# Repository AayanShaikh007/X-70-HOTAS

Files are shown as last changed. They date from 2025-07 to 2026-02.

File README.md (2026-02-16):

# X-70 HOTAS

A throttle and joystick HOTAS system designed from the ground up. Modelled after the X-56 HOTAS by Logitech. 

The X-70 HOTAS is a flight control system designed for use in flight sims and space sims. HOTAS stands for Hands on Throttle and Stick, and they are used to control planes in flight simulators just like how Airbus pilots and fighter pilots use a joystick to control the plane's movements. I designed both the throttle and the joystick in this project, down to the very mechanism that their motion relies on. The X-70 is highly customizable and has a bunch of useful features that increase realism, including landing gear and flap change levers, various customizable switches, and a touchscreen display that can be customized to activate more features and display data. 

I was motivated to make this project mainly by my own interest in flight sims but also due to the fact that there arent many HOTAS systems on the market right now that have a comparable amount of features for a reasonable price. For instance, the Turtle Beach VelocityOne flightdeck goes for around $500 CAD, which isnt very affordable. There is a lack of a affordable mid series detached HOTAS system that is still capable and reliable. 

## Software
I intend on using FreeJoy, a open source software to configure and run the joystick and throttle. It should allow me to easily configure the parts and make it much easier to debug issues and reduce workload since I wouldnt have to make a entire software just for the hotas. 

Freejoy: https://github.com/FreeJoy-Team/FreeJoy 

## Wiring Diagram
The wiring diagram is located inside the PCB folder as wiringdiagram.pdf. This will apply for throttle, the joystick does not need a matrix board but I may add one for convencience (I will get 5 pcbs from jlcpcb anyways). 

# Project Showcase







# BOM 
| Item | Amount | Bought? | Cost (CAD) | Total Cost | Notes | Link |
|---|---|---|---|---|---|---|
| Bluepill Microcontroller | 2 | n | 5.65 | 11.3 | | [Link](https://www.aliexpress.com/item/1005004918334754.html) |
| usb c to a cables | 2 | n | 2.86 | 5.72 | | [Link](https://www.aliexpress.com/item/1005007504310983.html) |
| toggle switches | 6 | n | 4.10 | 24.6 | | [Link](https://www.aliexpress.com/item/1005001315963290.html) |
| potentiometers (7mm thread) | 5 | n | 2.53 | 12.65 | cheapest option | [Link](https://www.aliexpress.com/item/1005005661105692.html) |
| rotary encoders (7mm thread)| 6 | n | 4.83 | 28.98 | looking for alternatives | [Link](https://www.aliexpress.com/item/1005007737001031.html) |
| large momentary switch | 1 | n | 6.63 | 6.63 | | [Link](https://aliexpress.com/item/4001169879232.html) |
| large latching switch | 1 | n | 6.76 | 6.76 | | [Link](https://aliexpress.com/item/4001169879232.html) |
| mini joysticks | 3 | n | 2.17 | 6.51 | kinda small but should work | [Link](https://www.aliexpress.com/item/1005007260466379.html) |
| large rgb metal button | 2 | n | 1.92 | 3.84 | | [Link](https://www.aliexpress.com/item/4000830670631.html) |
| hat switches 8 way | 3 | n | 4.57 | 13.71 | should be able to print cap | [Link](https://www.aliexpress.com/item/1005002969535551.html) |
| tricolor landing lights | 3 | n | 3.31 | 9.93 | | [Link](https://www.aliexpress.com/item/1005006314855864.html) |
| Nextion Enhanced | 1 | n | 27.2 | 27.2 | lots of models, shipping will vary | [Link](https://www.aliexpress.com/item/4001240732911.html) |
| 5x11x5 bearings | 2 | n | 1.38 | 2.76 | | [Link](https://www.aliexpress.com/item/1005006224445582.html) |
| m5x22 max screws | 4 | n | 0.51 | 2.03 | different size | [Link](https://www.aliexpress.com/item/1005005879037174.html) |
| M3x0.5 by 7 max screws | 6 | n | 1.38 | 1.38 | | [Link](https://www.aliexpress.com/item/1005004527586307.html) |
| m5 by 30 max screws | 8 | n | 0.42 | 3.36 | different size | [Link](https://www.aliexpress.com/item/1005005879037174.html) |
| springs | 4 | n | 5.01 | 5.01 | | [Link](https://www.aliexpress.com/item/1005006443579464.html) |
| hall effect sensors | 2 | n | 8.39 | 8.39 | | [Link](https://www.aliexpress.com/item/1005008473344808.html) |
| PCB manufacturing | 1 | n | 4.74 | 4.74 | | no link |

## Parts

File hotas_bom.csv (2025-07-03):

Item | Amount | Bought? | Cost (CAD) | Total Cost | Notes | Link
Bluepill Microcontroller | 2 | n | 5.65 | 11.3 |  | https://www.aliexpress.com/item/1005004918334754.html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
usb c to a cables | 2 | n | 2.86 | 5.72 |  | https://www.aliexpress.com/item/1005007504310983.html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
toggle switches | 6 | n | 4.10 | 24.6 |  | https://www.aliexpress.com/item/1005001315963290.html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
potentiometers (7mm thread) | 5 | n | 2.53 | 12.65 | cheapest option | https://www.aliexpress.com/item/1005005661105692.html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
rotary encoders (7mm thread) | 6 | n | 4.83 | 28.98 | looking for alternatives | https://www.aliexpress.com/item/1005007737001031.html?scm_id=1007.40050.354490.0&scm-url=1007.40050.354490.0
large momentary switch | 1 | n | 6.63 | 6.63 |  | aliexpress.com/item/4001169879232.html?spm=a2g0o.productlist.main.1.23fdLvQCLvQCRK&algo_pvid=6f283221-de15-417a-9911-344e72dfff53&algo_exp_id=6f283221-de15-417a-9911-344e72dfff53-0&pdp_ext_f=%7B"order"%3A"358"%2C"eval"%3A"1"%7D&pdp_npi=4%40dis%21CAD%216.68%215.57%21%21%214.76%213.97%21%402103205217508267992468400e6bad%2110000015016525249%21sea%21CA%210%21ABX&curPageLogUid=WL6grQlmlbEs&utparam-url=scene%3Asearch%7Cquery_from%3A#nav-description
large latching switch | 1 | n | 6.76 | 6.76 |  | aliexpress.com/item/4001169879232.html?spm=a2g0o.productlist.main.1.23fdLvQCLvQCRK&algo_pvid=6f283221-de15-417a-9911-344e72dfff53&algo_exp_id=6f283221-de15-417a-9911-344e72dfff53-0&pdp_ext_f=%7B"order"%3A"358"%2C"eval"%3A"1"%7D&pdp_npi=4%40dis%21CAD%216.68%215.57%21%21%214.76%213.97%21%402103205217508267992468400e6bad%2110000015016525249%21sea%21CA%210%21ABX&curPageLogUid=WL6grQlmlbEs&utparam-url=scene%3Asearch%7Cquery_from%3A#nav-description
mini joysticks | 3 | n | 2.17 | 6.51 | kinda small but should work | https://www.aliexpress.com/item/1005007260466379.html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
large rgb metal button | 2 | n | 1.92 | 3.84 |  | https://www.aliexpress.com/item/4000830670631.html?scm_id=1007.40050.354490.0&scm-url=1007.40050.354490.0 or https://www.aliexpress.com/item/1005006477375437.html?scm_id=1007.40050.354490.0&scm-url=1007.40050.354490.0
hat switches 8 way | 3 | n | 4.57 | 13.71 | should be able to print cap | https://www.aliexpress.com/item/1005002969535551.html?scm_id=1007.40050.354490.0&scm-url=1007.40050.354490.0
tricolor landing gear lights | 3 | n | 3.31 | 9.93 |  | https://www.aliexpress.com/item/1005006314855864.html?scm_id=1007.10668.445195.0&scm-url=1007.10668.445195.0
Nextion Enhanced | 1 | n | 27.2 | 27.2 | lots of models, shipping will vary | https://www.aliexpress.com/item/4001240732911.html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
5x11x5 bearings | 2 | n | 1.38 | 2.76 |  | https://www.aliexpress.com/item/1005006224445582.html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
m5x22 max screws | 4 | n | 0.51 | 2.030266667 | different size | https://www.aliexpress.com/item/1005005879037174.html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
M3x0.5 by 7 max screws | 6 | n | 1.38 | 1.38 |  | https://www.aliexpress.com/item/1005004527586307.html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
m5 by 30 max screws | 8 | n | 0.42 | 3.36 | different size | https://www.aliexpress.com/item/1005005879037174.html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
springs | 4 | n | 5.01 | 5.01 |  | https://www.aliexpress.com/item/1005006443579464.html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
hall effect sensors | 2 | n | 8.39 | 8.39 |  | https://www.aliexpress.com/item/1005008473344808.html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
PCB Manufacturing | 1 | n | 4.74 | 4.74
 |  |  | CAD | USD
 |  | Total Cost | 185.50 | 136.45
 |  |  |  | Note: 150 USD = 204.58 CAD

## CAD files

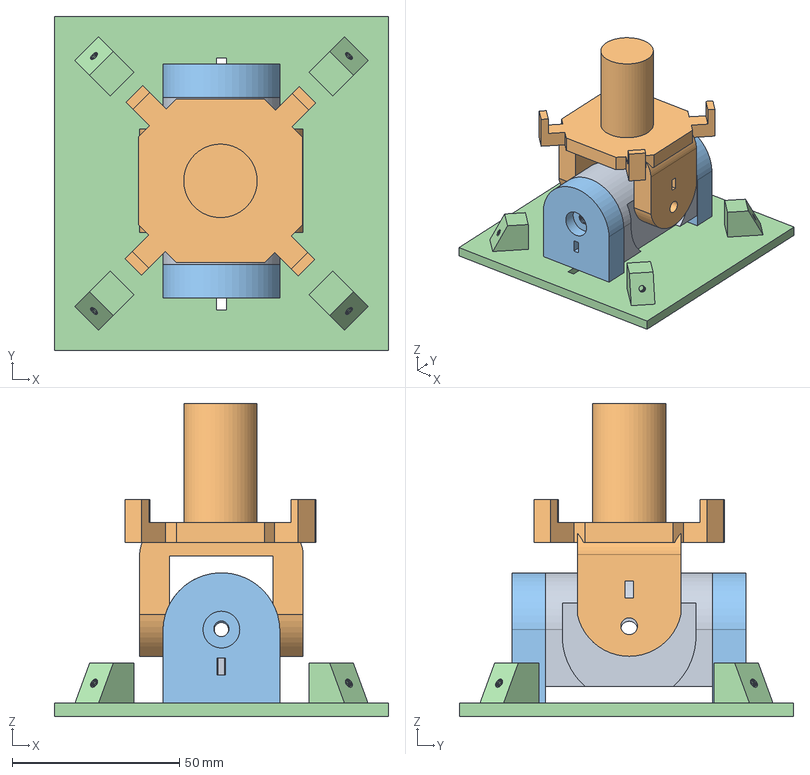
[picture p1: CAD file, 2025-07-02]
CAD/joystick_assembled v13.step
100.0 x 100.0 x 93.8 mm
roll
pitch
roll brackets x 2
base

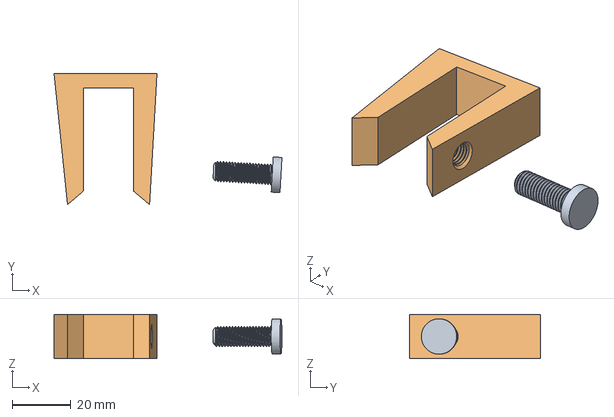
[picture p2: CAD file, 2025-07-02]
CAD/clamp v2.step
77.5 x 44.6 x 15.0 mm
bolt

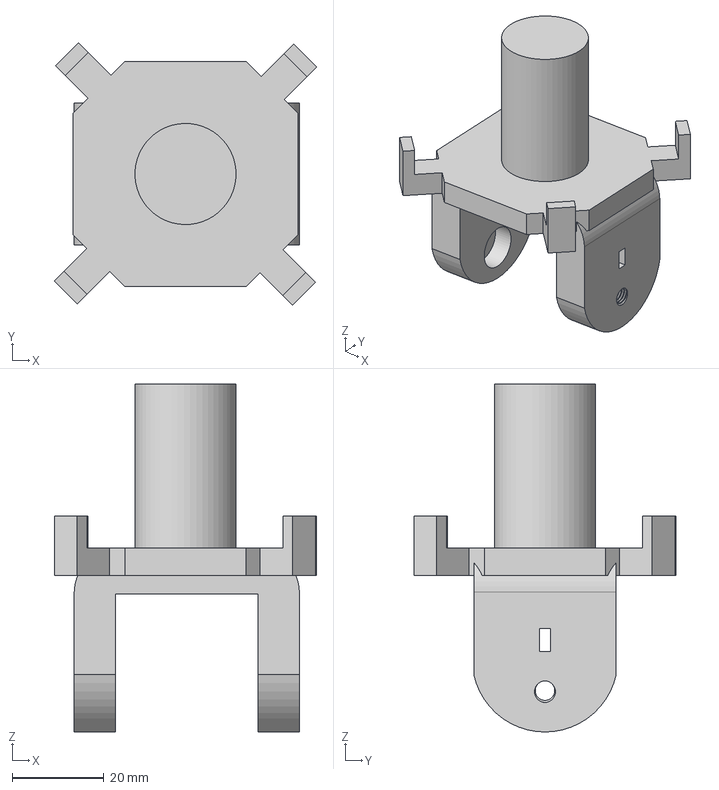
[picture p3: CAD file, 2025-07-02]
CAD/pitch v12.step
57.1 x 57.1 x 75.7 mm

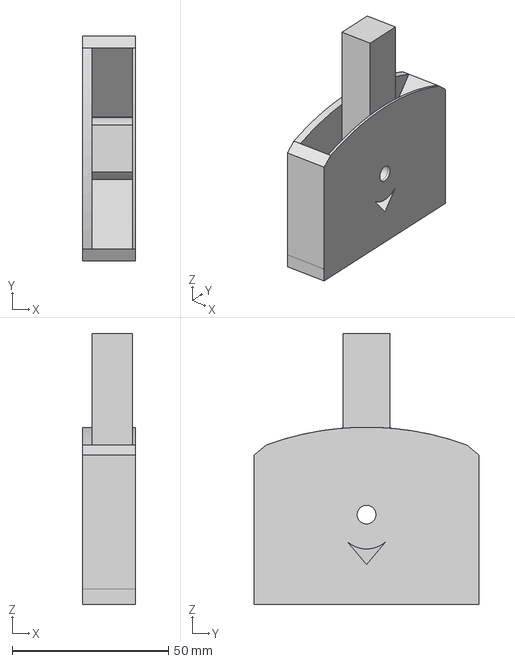
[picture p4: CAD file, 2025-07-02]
CAD/throttle_mech v6.step
17.0 x 72.0 x 86.8 mm

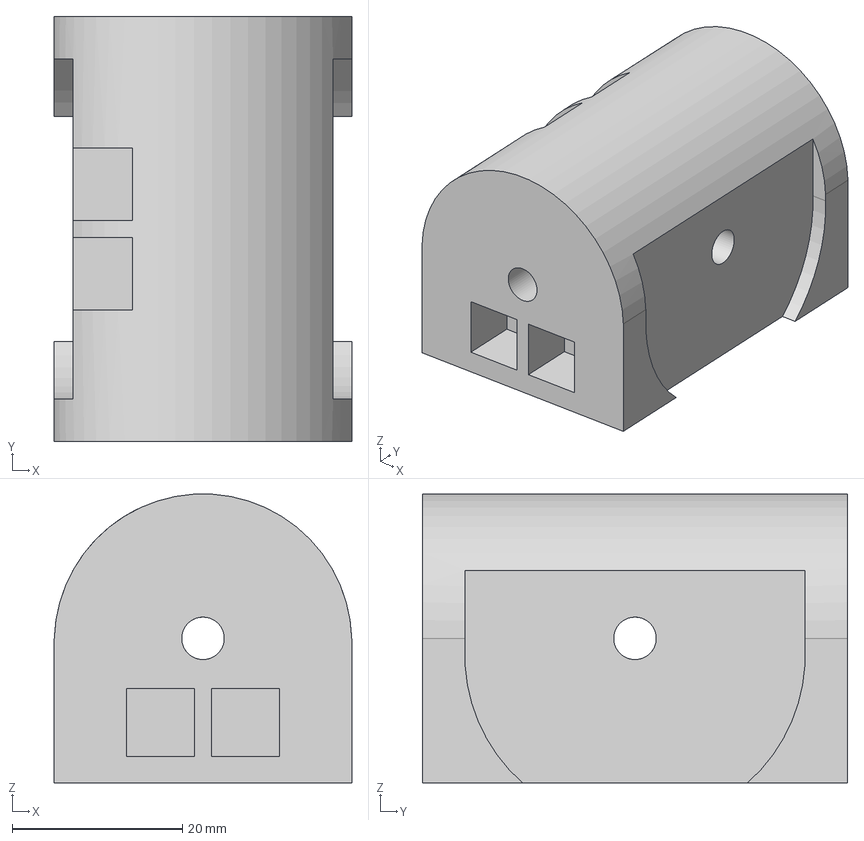
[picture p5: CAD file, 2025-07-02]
CAD/roll v9.step
35.0 x 50.0 x 34.0 mm

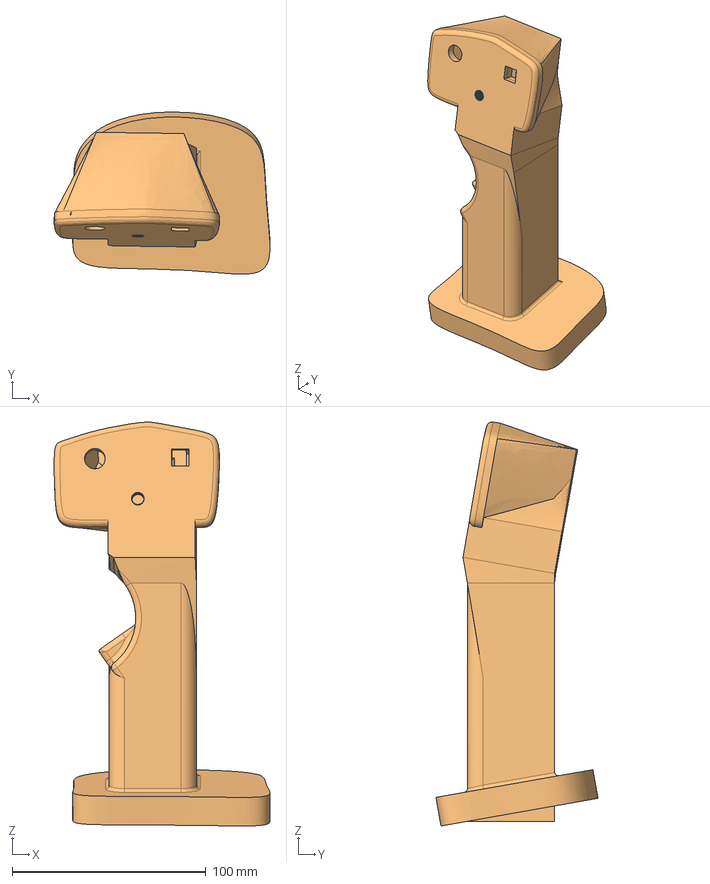
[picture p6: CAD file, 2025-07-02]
CAD/joystick v10.step
111.4 x 83.7 x 208.6 mm

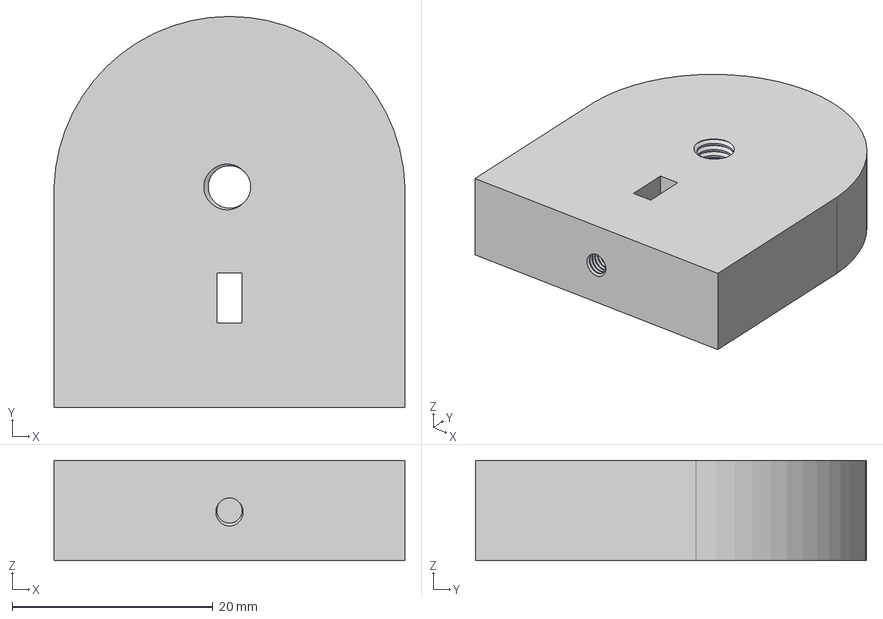
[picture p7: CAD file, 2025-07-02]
CAD/roll brackets v8.step
35.0 x 39.0 x 10.0 mm

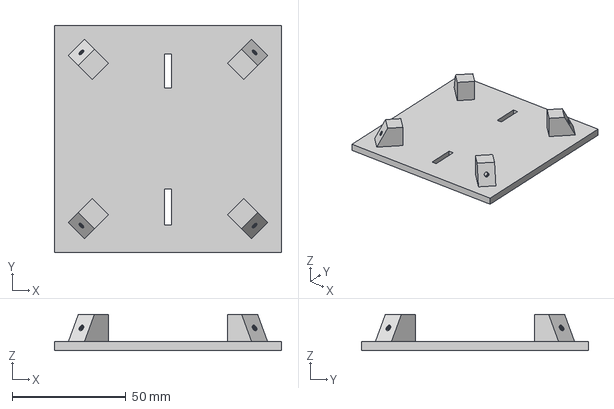
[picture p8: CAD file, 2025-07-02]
CAD/base v9.step
100.0 x 100.0 x 16.0 mm

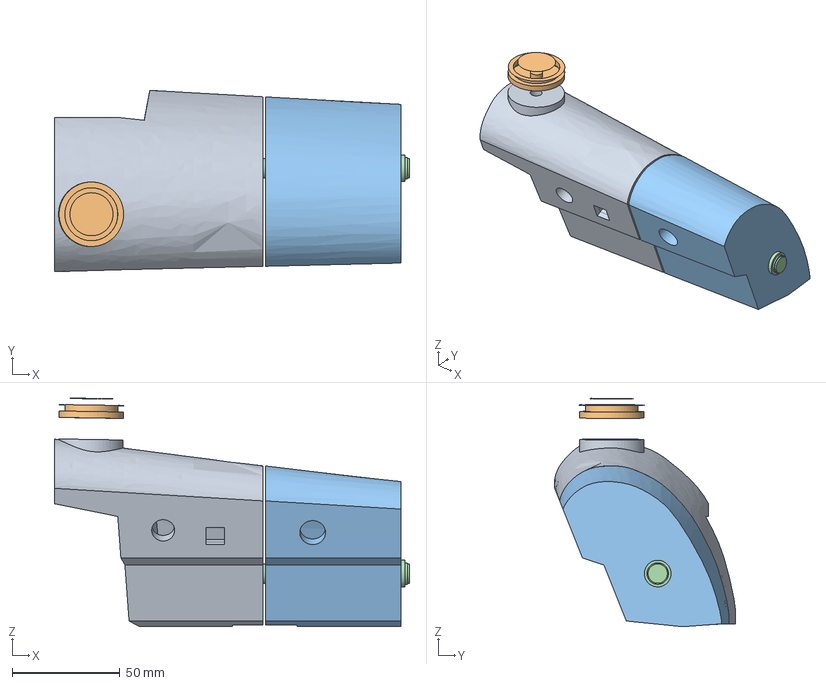
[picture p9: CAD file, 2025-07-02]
CAD/throttle_handle v10.step
165.0 x 84.3 x 106.2 mm

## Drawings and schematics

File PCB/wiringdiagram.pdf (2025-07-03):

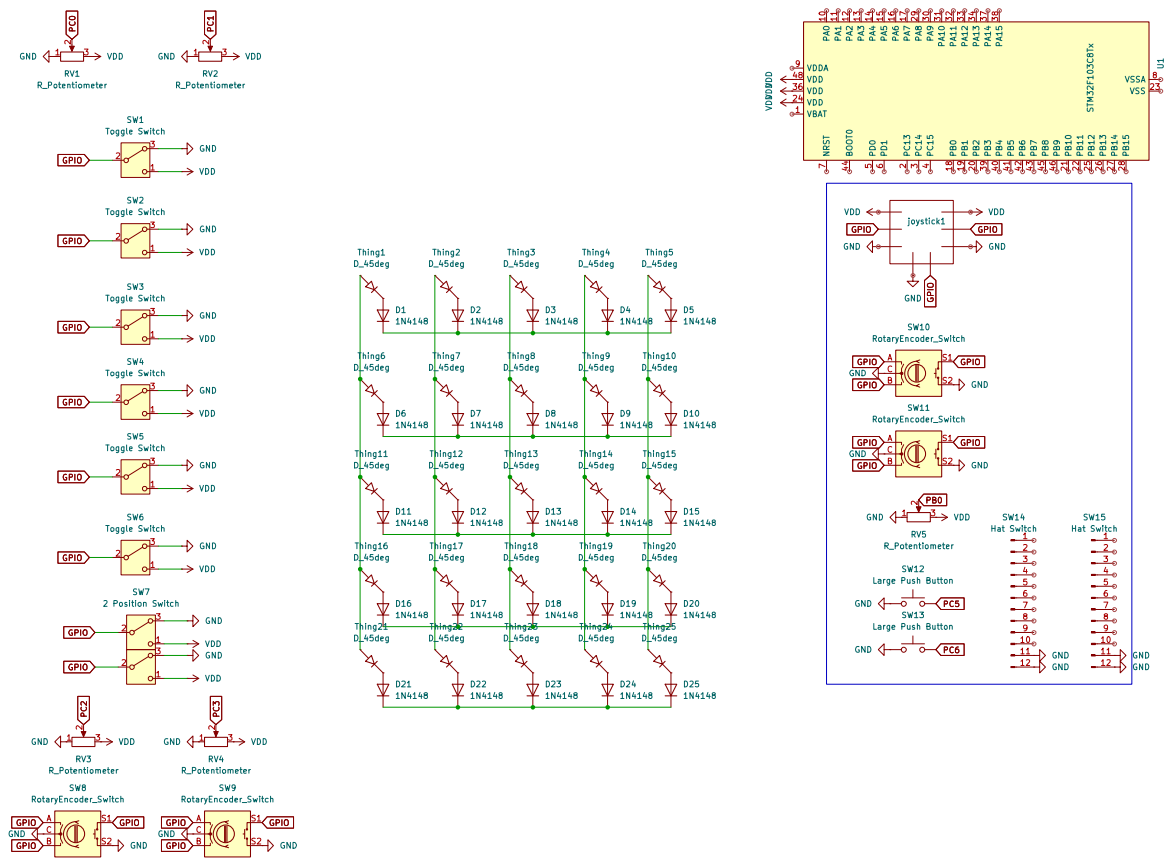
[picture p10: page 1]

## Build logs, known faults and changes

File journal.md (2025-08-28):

---
title: "X-70 HOTAS"
author: "@Scalar"
description: "A throttle and joystick HOTAS system for flight sims."
created_at: "2025-06-16"
---

# X-70 HOTAS Journal --> 49 Hours total (not including assembly)
First- a small word on the complexity of the project. I think this was a particularly difficult project and should be considered to take 50+ hours since I will likely be making various edits and changes in the future as I prototype the throttle and joystick mechanisms and expereiment with making new ones. Furthermore, assembly and software configuration will also take quite some time. 

# June 16th- spent 4 hours planning. 
I spent most of today setting my goals for the project. In summary, I want to make a HOTAS system that resembles the X-56 HOTAS by Logitech, since I like its design. 

_Aims for CAD design_
- X and Y moving body, detect position via hall effect sensors
- Ergonomic flight stick
- Analog trigger spring mechanisms

_Aims for electronics_
- Force feedback
- Use FreeJoy and any STM32F103 ("Blue Pill"). This removes the need for software. 
- Hall effect (Trigger, X-Y axis sensing)
- 2 Hat switches
- 5 buttons, 3 top, 2 sides. 
- One trigger switch. 
- OLED display
- RGB panel on back of body (backlight will be viewable.

_X-56 HOTAS By Logitech_



# June 17th- Spent 8 hours modelling flight stick.

- Designed pitch and roll mechanism, as well as the pitch mechanism holders. 
- Used Revolute feature (for the first time) to test movement in the Y axis, then the X axis. 
- Stick moves 18 degrees in the Y axis (along the longer side of the assembly), moves 15 degrees in the other X axis. 
- These are very good values- they are within or exceed the values of existing flight sticks. I am very happy that it worked and didnt require a bunch of trial and error. 
- I then tested movement in both axes to see if there are any conflicts. 
- According to the program, there should not be any problems when moving in both axes. Since I recently got a 3d printer, I will be able to prototype this before submission. 
- Sizing appears to be just right.
- Next, I will do some research on what specific hall effect sensor to use and where to place it. 
- Parts used for this iteration: 5x11x5 bearings, m5 screws, M3 by 7 max screws

_Image of the flight stick assembly that will be housed within the base._



# June 18th (early morning)- Spent 4 hours modelling. 

- Focused on designing the joystick itself. I started this part of the design process thinking it would take a lot of trial and error but if anything, it took a lot of thought to ensure that the parts would actually be ergonomic and fit real world dimensions.
- Used images of the X-56 as reference (didnt copy obviously) to base design off.
- Pretty happy with the result, I will do some more refining later as I alter the design for buttons and wiring. I am not completely satisfied with it, but I think that with some polishing it can look even closer to the Logitech X-56 that I am modelling it after. 
- One issue that was particularly annoying was the fact that it was difficult to simply make a shell of the outer design using the built in mode, so I will need to do it manually. 




# June 18th (Evening)- Spent 5 hours modelling throttle.

- My aim for today was to finish the throttle design, and although I am pretty close to completion, I was unable to finish it completely. 
- To take a break from the joystick, I transitioned to working on the throttle design. 

_Aims for throttle_:
- RGB Lighting for Button Lettering, RGB backlight (back panel) 
- Various customizable switches
- System to add resistance to the throttle lever
- Split throttle design.

So far, I have completed the mechanism for the throttle- the position will be sensed by a potentiometer, and the throttle itself will move a total of 80 degrees if no future designs collide or interfere with it. It has been designed with tight tolerances with the hope that it would create some friction between the moving parts. My alternative method to add resistance to the throttle lever movement is two C-clamps that will compress the throttle lever body and increase the amount of friction it experiences. **It will be essential to print the parts in a very specific orientation so that the parts do not give the impression that they are 3d printed when moved.**

_Rough preview of the throttle body._



# June 20th

Got busy with some assignments and the last day of school yesterday. With that out of the way now, I have a couple of changes that I would like to make to the project goals. Inspired by the turtle beach throttle, I have decided to add a rotary switch that can control flaps, a switch to control landing gear and a large LCD to show data. I may also add an oled display to the throttle as done in the turtle Beach throttle.

# June 24th- 6 hours worked 

Got some good progress done today. Firstly, I got a lot of progress in the throttle body design, and I am very happy with how it turned out. I have added a rotating knob that can be customized for various uses, and intend on adding a hat switch and some other switches in a bit. However, it probably doesnt look as good right now because I havent added the final touches to the appearance. 



I also started resaerching IO options and arranged the layout for the IO on the throttle top shield. I will be using a variety of ~2cm toggle switches, a rotating switch, and **a flap setting lever**. This lever is going to be one of the most used parts on the throttle, so it is essential that I get it right.  



# June 25th and 26th- 3 Hours spent

At this point I think I am finished with the throttle design and all that is left is the finishing touches such as the logo and fillets. The throttle now has places for the components to be screwed into or secured with glue. Due to the positions of the buttons I will not be using a PCB in the tradition sense in the throttle, and will probably not use one in the joystick either. 



I then worked to finish the joystick design by creaing the spaces for the components, and creating holes and screws for the buttons and components to go. One new component I added was a rotary encoder, which I thought would be a good idea since it can combine a potentiometer and button in function (mostly). At this point, the only thing left to work on is the joystick assembly and base. 



# June 26 to 30th (worked sporadically)- 12 hours spent over time.
As mentioned previously, the main focus now is just to add the finishing touches such as adding holes and accomodating for wires. I completed the joystick base, where I decided on a relatively minimalistic design with just a landing gear lever and landing gear indicator lights, a large rotary encoder, and a sensitive touchscreen that I can easily create the GUI for on the PC. I forgot to take a screenshot of the joystick base that day. Following that, I made some changes to the joystick design that needed to be made because I decided to tilt the entire stick 10 degrees forward for ergonomics. However, I somehow lost the ability to add the fillet to the joystick that would give it the characteristic place to insert your thumb, I will continue to try to fix this, although it is not a major issue. 

To make the HOTAS system look as flawless and polished as possible, I added my personal logo that I made a few weeks ago to place on my PCBs and 3d prints going forward. I also created a SVG of a stylistic logo that I could print on the back of both assemblies to further add to the appearance of the HOTAS system.

# July 2nd- worked 7 hours on PCB, BOM, shipping project
Turns out I actually will need a PCB, since I have 50 pins of switches and stuff to connect to the board. I made a matrix board that reduces that to around 30 pins or so. 



# Final showcase of finished product:







Joystick:





Looking forward to building this irl!

# August 3rd
Printed some of the components and started assembling them. I also started testing the throttle mechanism and the joystick in the freejoy software. Fortunately no issues were found and the throttle actually worked in X-Plane 11!!!



# August 5th
Today I will be spending a lot of time trying to print the rest of the assembly, including the throttle handle, joystick, and the enclosure for both the joystick and throttle. I am aiming to print all of the parts by tomorrow morning so that I can start assembly early tomorrow. 



# August 6th
Finished the assembly of all of the components. Soldered the switches and wired them, which took quite some time since each switch had 3 terminals to wire. Wired the buttons and joysticks etc. I found superglue to be very helpful in attaching the components together (the components that couldnt be bolted together). Tested the components on X-Plane and MSFS 2020 and got both the joystick and the throttle to work. 



# August 27th 
Today I went back to this project to finalize the demo video and to fix a small problem that had been annoying me for some time. I didnt like how the joystick hall effect sensors had a lot of noise, which may be visible in one of the videos where you can see the joystick as its being assembled. I found a feature in FreeJoy where you could de-noise the signal by adding a "Filter" of varying strengths, which solved the issue. 
